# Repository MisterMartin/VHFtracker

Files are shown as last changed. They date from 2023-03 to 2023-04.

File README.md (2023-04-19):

# VHFtracker

Based on Teensy support provided by PJRC.

## Arduino Configuration
- Select the Teensy 3.6 board.
- Set the CPU speed to 24MHz.
## Hardware Revisions

Different I/O pins were used for some functions. A #define in the Arduino
sketch is used to select the targeted board.

| Rev A | Rev B |REV A Pin|REV B Pin| Notes |
|---|---|---|---|---|
| 0_RX1_(GPS_TX) | 33_TX5_(GPS_RX) | 0*  | 33*  | Selected as Serial1 or Serial5 |
| 1_TX1_(GPS_RX) | 34_RX5_(GPS_TX) | 1*  | 34*  | Selected as Serial1 or Serial5 |
| 2_TX_ENABLE | 16_TX_ENABLE | 2*  | 16*  | |
| A21_TX_AUDIO | DAC0 | 21 | 21 | |
| 18_SDA0_(PRESS)| (N/A) | 18 | | |
| 19_SCL0_(PRESS)| (N/A) | 19 | | |
| A6_3V7_VMON |(VMON UNLABELED) | 20 | 20 | |
| 23_5V_SHTDWN | 15_5V_SHTDWN | 23*  | 15*  | |
| 30_GPS_PWR_EN  | 36_GPS_PWR_EN | 30*  | 36*  | |
| 31_GPS_EXTINT  | | 31 | | How is this handled for Rev B? |
| 32_GPS_RST | | 32 | | How is this handled for Rev B? |

\* = signals that must be (re)defined based on the board revision.
## Arduino IDE

- The previous IDE was a pre-packaged by PRJC, as a modified version of Arduino IDE v1.x, 
  and ran as Teensyduino.
- PJRC released a board support package which now works with Arduino IDE v2.X. Install the
  Arduino IDE first, and then configure Teensy support, found on 
  the [PRJC download page](https://www.pjrc.com/teensy/td_download.html).
- For some reason, the board manager wouldn't read the PRJC board URL. I experimented with
  manually editing ~/.arduinoIDE/arduino-cli.yaml to add the URL, and restarting the 
  IDE multiple times. It finally read the URL and provided the Teensy in the boards list.
  Perhaps the issue was due to the slow Internet access from McMurdo.

## Tracker Code

- It turned out that the +5V control was not being used for the encoded ping. For Rev A,
  the ping was working because although the 5V shutdown was disabling the 5V regulator,
  power was still available to the op amp via a bypass diode. The switch that was added
  in Rev B prevented this, and the ping was not working. Once the code was corrected,
  the ping started working.

## Batteries

- In the 2019 deployment, a couple of the trackers failed because the commercial battery
  holders were breaking during landing impact. New holders were designed and fabricated on
  the 3d printer. Three designs were created and printed:
    - For Rev A: a single D cell holder for a battery with welded tabs. Hot glue holds the
      battery in at the open end.
    - For Rev B: a holder for 4 AA cells, with open ends for batteries with soldered/welded
      connections. Our batteries would not take solder, so these wer not used.
    - For Rev B: a holder for 4 AA cells, with no openings. Salvaged steel strips were used
      to make contacts. This design was flown.

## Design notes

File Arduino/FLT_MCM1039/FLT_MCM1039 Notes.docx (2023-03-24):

• Software changed: June 19, 2019

• PWB S/N: 409

• R1 removed

• Jumper SJ1 set for battery power

• Flight name\mode messages

• PRE_MSG "1038_PRE"

• TRK_MSG "1038_TRK"

• TRK_GPS "1038_GPS"

• PING_ID 38

• Timing parameters for the flight

• PreFlight Time = 2 hours (120 minutes), APRS XMIT every 10 minutes

• PREFLIGHT_APRS_TX_PERIOD 10

• MAX_PREFLIGHT_PACKETS 12

• 10*12 = 120

• GPS search time: 2 minutes

• Flight Time = 2 hours

• FLIGHT_TIME 120

• GPS search time: 2 minutes

• Hibernate\Sleep time

• Launch: March 29, 2023, Julian Day: 88

• Wake up: November 16, 2023, Julian Day: 320

• Number of days to hibernate 320 – 88 = 232

• HIBERNATE_PERIOD 232

• GPS search time: 5 minutes

• Track mode

• Update GPS position every 24 hours

• TRACK_GPS_PERIOD 24

• Send APRS GPS position every 10 minutes when in Track mode

• TRACK_APRS_TX_PERIOD 10

• Send pings every 15 seconds when in Track mode

• TRACK_PING_TX_PERIOD 15

• Three Audio pings 75 msec at 700 Hz per minute

• One encoded data ping per minute

• GPS search time: 3 minutes

Changes from FLT_1036

• None

Initial Power up Test

• Five Flashes

• First three messages after power up:

10:10:31, PRE__FLT, 000/001, 0000.00N, 00000.00E

10:21:00, 1037_PRE, 000/002, 7750.86S, 16639.94E

10:31:01, 1037_PRE, 000/003, 7750.86S, 16639.94E

• GPS position is correct

• Crary Lab: 77° 50.86’ (77.847°), 166° 39.96’ (166.666°)

13 June 2019

• Initial Battery Voltage = 3.658V

• Super Capacitor Charge Voltage = 3.696V

• Battery voltage after initial power on test = 3.568V

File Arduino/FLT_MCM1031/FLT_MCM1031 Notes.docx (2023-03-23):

FLT_MCM1031

- Software changed: May 28, 2019
- PWB S/N: 404
  - R1 removed
  - Jumper SJ1 set for battery power
- Flight name\mode messages
  - PRE_MSG "1031_PRE"
  - TRK_MSG "1031_TRK"
  - TRK_GPS "1031_GPS"
  - PING_ID 31
- Timing parameters for the flight
  - PreFlight Time = 2 hours (120 minutes), APRS XMIT every 10 minutes
    - PREFLIGHT_APRS_TX_PERIOD 10
    - MAX_PREFLIGHT_PACKETS 12
    - 10*12 = 120
    - GPS search time: 2 minutes
  - Flight Time = 2 hours
    - FLIGHT_TIME 120
    - GPS search time: 2 minutes
  - Hibernate\Sleep time
    - Launch: Wednesday, May 29, 2019, Julian Day: 149
    - Wake up: Friday, November 1, 2019, Julian Day: 305
    - Number of days to hibernate 305 – 149 = 156
    - HIBERNATE_PERIOD 156
    - GPS search time: 5 minutes
  - Track mode
    - Update GPS position every 24 hours
      - TRACK_GPS_PERIOD 24
    - Send APRS GPS position every 10 minutes when in Track mode
      - TRACK_APRS_TX_PERIOD 10
    - Send pings every 15 seconds when in Track mode
      - TRACK_PING_TX_PERIOD 15
      - Three Audio pings 75 msec at 700 Hz per minute
      - One encoded data ping per minute
    - GPS search time: 3 minutes

Changes from FLT_1030

- Changed Output_Ping_tone() function so it passes tone frequency and tone pulse length parameters
- Changed audio ping from 500 Hz to 704 Hz
  - 704 Hz seems more audible than 500 Hz

Initial Power up Test

- Five Flashes
- First three messages after power up:

9:18:19, PRE__FLT, 000/001, 0000.00N, 00000.00E

9:29:59, 1031_PRE, 000/002, 7750.86S, 16639.94E

9:40:00,1 031_PRE, 000/003, 7750.86S, 16639.94E

- GPS position is correct
  - Crary Lab: 77° 50.86 (77.847°), 166° 39.94’ (166.665°),

28 May 2019

- Initial Battery Voltage = 3.657V
- Super Capacitor Charge Voltage = 3.700V
- Installed initial battery voltage = 3.664 V
- Installed battery and plugged in voltage = 3.600 V

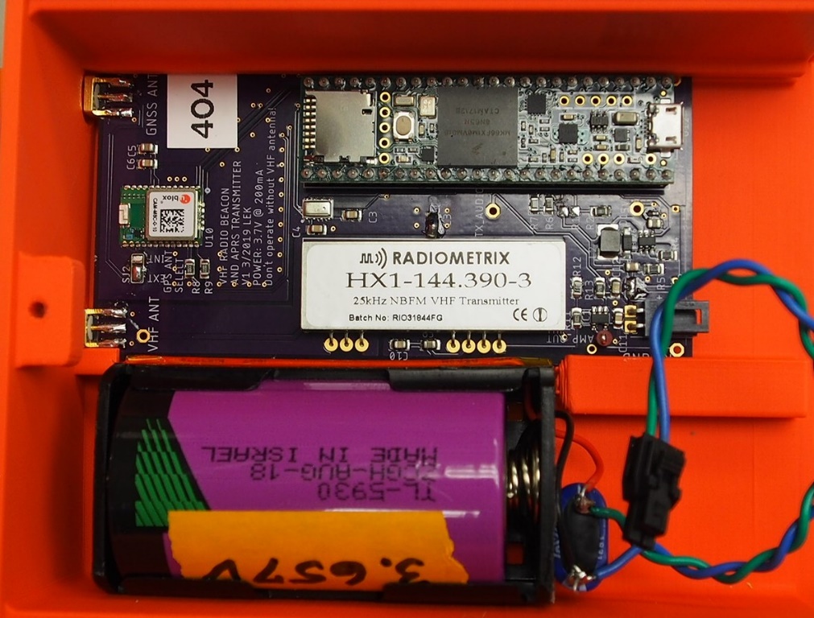
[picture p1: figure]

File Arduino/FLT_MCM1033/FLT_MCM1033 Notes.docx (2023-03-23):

- Software changed: June 7, 2019
- PWB S/N: 408
  - R1 removed
  - Jumper SJ1 set for battery power
- Flight name\mode messages
  - PRE_MSG "1033_PRE"
  - TRK_MSG "1033_TRK"
  - TRK_GPS "1033_GPS"
  - PING_ID 33
- Timing parameters for the flight
  - PreFlight Time = 2 hours (120 minutes), APRS XMIT every 10 minutes
    - PREFLIGHT_APRS_TX_PERIOD 10
    - MAX_PREFLIGHT_PACKETS 12
    - 10*12 = 120
    - GPS search time: 2 minutes
  - Flight Time = 2 hours
    - FLIGHT_TIME 120
    - GPS search time: 2 minutes
  - Hibernate\Sleep time
    - Launch: June 8, 2019, Julian Day: 159
    - Wake up: November 16, 2019, Julian Day: 320
    - Number of days to hibernate 320 – 159 = 161
    - HIBERNATE_PERIOD 166
    - GPS search time: 5 minutes
  - Track mode
    - Update GPS position every 24 hours
      - TRACK_GPS_PERIOD 24
    - Send APRS GPS position every 10 minutes when in Track mode
      - TRACK_APRS_TX_PERIOD 10
    - Send pings every 15 seconds when in Track mode
      - TRACK_PING_TX_PERIOD 15
      - Three Audio pings 75 msec at 700 Hz per minute
      - One encoded data ping per minute
    - GPS search time: 3 minutes

Changes from FLT_1031

- None
- Note: FLT 1032 was an ROPC flight and had no VHF tracker

Initial Power up Test

- Five Flashes
- First three messages after power up:

9:22:21, PRE__FLT, 000/001, 0000.00N, 00000.00E

9:33:01, 1033_PRE, 000/002, 7750.86S, 16639.94E

9:43:02, 1033_PRE, 000/003, 7750.86S, 16639.94E

- GPS position is correct
  - Crary Lab: 77° 50.86’ (77.847°), 166° 39.94’ (166.665°)

29 May 2019

- Initial Battery Voltage = 3.650V
- Super Capacitor Charge Voltage = 3.690V
- Installed initial battery voltage = 3.664 V
- Battery voltage after initial power on test = 3.583 V

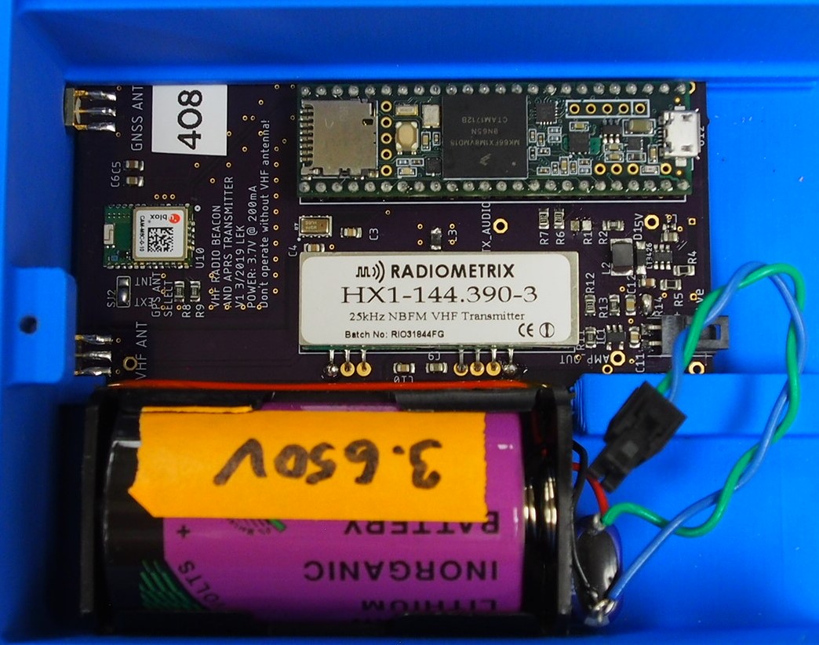
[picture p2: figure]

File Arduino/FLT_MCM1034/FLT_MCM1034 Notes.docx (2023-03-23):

- Software changed: June 7, 2019
- PWB S/N: 405
  - R1 removed
  - Jumper SJ1 set for battery power
- Flight name\mode messages
  - PRE_MSG "1034_PRE"
  - TRK_MSG "1034_TRK"
  - TRK_GPS "1034_GPS"
  - PING_ID 34
- Timing parameters for the flight
  - PreFlight Time = 2 hours (120 minutes), APRS XMIT every 10 minutes
    - PREFLIGHT_APRS_TX_PERIOD 10
    - MAX_PREFLIGHT_PACKETS 12
    - 10*12 = 120
    - GPS search time: 2 minutes
  - Flight Time = 2 hours
    - FLIGHT_TIME 120
    - GPS search time: 2 minutes
  - Hibernate\Sleep time
    - Launch: June 8, 2019, Julian Day: 159
    - Wake up: November 16, 2019, Julian Day: 320
    - Number of days to hibernate 320 – 159 = 161
    - HIBERNATE_PERIOD 161
    - GPS search time: 5 minutes
  - Track mode
    - Update GPS position every 24 hours
      - TRACK_GPS_PERIOD 24
    - Send APRS GPS position every 10 minutes when in Track mode
      - TRACK_APRS_TX_PERIOD 10
    - Send pings every 15 seconds when in Track mode
      - TRACK_PING_TX_PERIOD 15
      - Three Audio pings 75 msec at 700 Hz per minute
      - One encoded data ping per minute
    - GPS search time: 3 minutes

Changes from FLT_1031

- None
- Note: FLT 1032 was an ROPC flight and had no VHF tracker

Initial Power up Test

- Five Flashes
- First three messages after power up:

8:54:00, PRE__FLT, 000/001, 0000.00N, 00000.00E

9:04:00, 1033_PRE, 000/002, 7750.86S, 16639.94E

9:14:00, 1033_PRE, 000/003, 7750.86S, 16639.94E

- GPS position is correct
  - Crary Lab: 77° 50.86’ (77.847°), 166° 39.98’ (166.666°)

30 May 2019

- Initial Battery Voltage = 3.658V
- Super Capacitor Charge Voltage = 3.698V
- Installed initial battery voltage = 3.600 V
- Battery voltage after initial power on test = 3.595 V

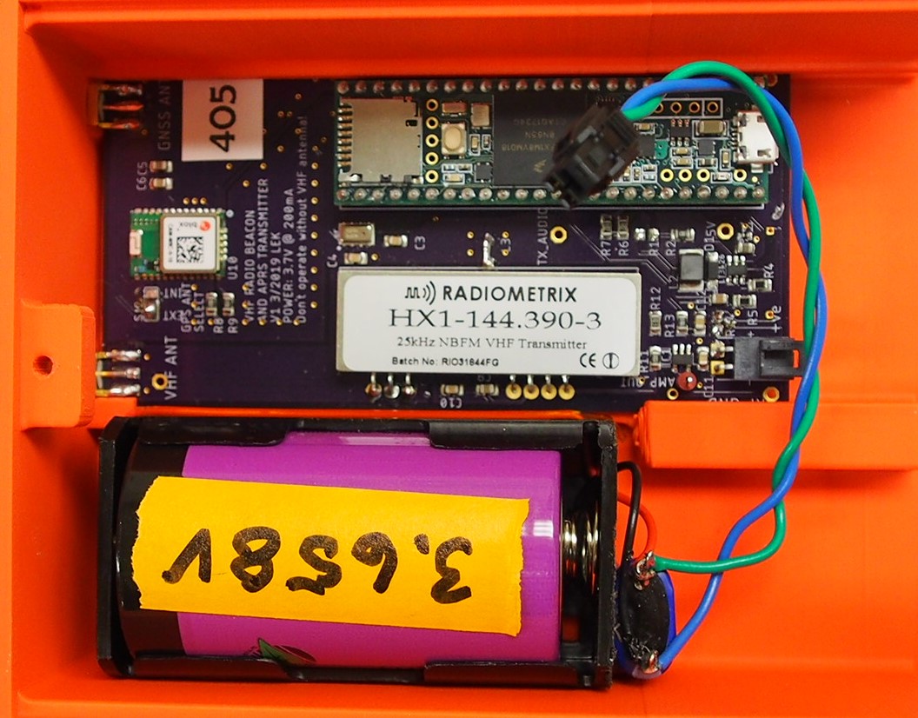
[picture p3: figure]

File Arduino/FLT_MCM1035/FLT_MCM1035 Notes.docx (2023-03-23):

- Software changed: June 19, 2019
- PWB S/N: 407
  - R1 removed
  - Jumper SJ1 set for battery power
- Flight name\mode messages
  - PRE_MSG "1035_PRE"
  - TRK_MSG "1035_TRK"
  - TRK_GPS "1035_GPS"
  - PING_ID 35
- Timing parameters for the flight
  - PreFlight Time = 2 hours (120 minutes), APRS XMIT every 10 minutes
    - PREFLIGHT_APRS_TX_PERIOD 10
    - MAX_PREFLIGHT_PACKETS 12
    - 10*12 = 120
    - GPS search time: 2 minutes
  - Flight Time = 2 hours
    - FLIGHT_TIME 120
    - GPS search time: 2 minutes
  - Hibernate\Sleep time
    - Launch: June 24, 2019, Julian Day: 175
    - Wake up: November 16, 2019, Julian Day: 320
    - Number of days to hibernate 320 – 175 = 145
    - HIBERNATE_PERIOD 145
    - GPS search time: 5 minutes
  - Track mode
    - Update GPS position every 24 hours
      - TRACK_GPS_PERIOD 24
    - Send APRS GPS position every 10 minutes when in Track mode
      - TRACK_APRS_TX_PERIOD 10
    - Send pings every 15 seconds when in Track mode
      - TRACK_PING_TX_PERIOD 15
      - Three Audio pings 75 msec at 700 Hz per minute
      - One encoded data ping per minute
    - GPS search time: 3 minutes

Changes from FLT_1034

- None

Initial Power up Test

- Five Flashes
- First three messages after power up:

14:25:15, PRE__FLT, 000/001, 0000.00N,00000.00E

14:35:48, 1035_PRE, 000/002, 7750.86S,16639.96E

14:45:49, 1035_PRE, 000/003, 7750.86S,16639.96E

- GPS position is correct
  - Crary Lab: 77° 50.86’ (77.847°), 166° 39.96’ (166.666°)

31 May 2019

- Initial Battery Voltage = 3.658V
- Super Capacitor Charge Voltage = 3.698V
- Installed initial battery voltage = 3.600 V
- Battery voltage after initial power on test = 3.584 V

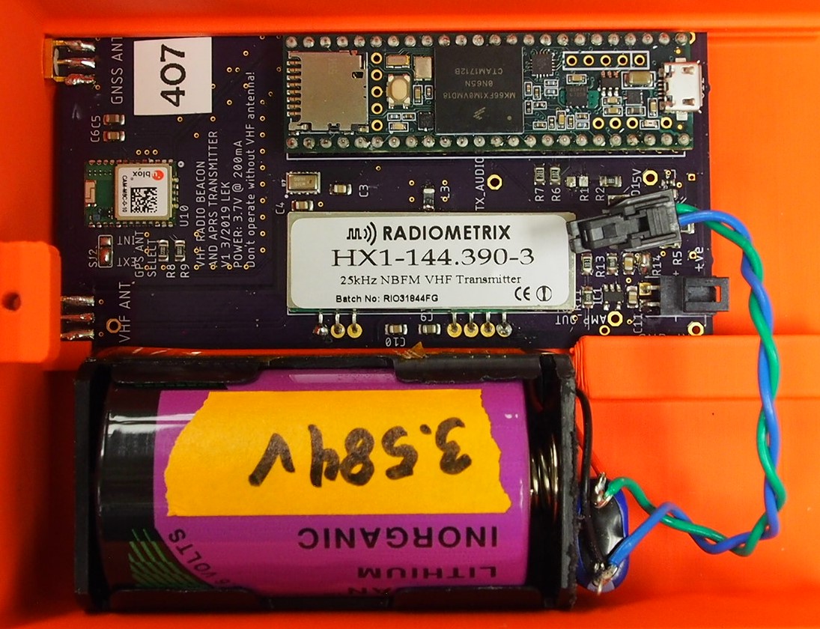
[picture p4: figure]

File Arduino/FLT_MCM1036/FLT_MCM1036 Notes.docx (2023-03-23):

- Software changed: June 19, 2019
- PWB S/N: 402
  - R1 removed
  - Jumper SJ1 set for battery power
- Flight name\mode messages
  - PRE_MSG "1036_PRE"
  - TRK_MSG "1036_TRK"
  - TRK_GPS "1036_GPS"
  - PING_ID 36
- Timing parameters for the flight
  - PreFlight Time = 2 hours (120 minutes), APRS XMIT every 10 minutes
    - PREFLIGHT_APRS_TX_PERIOD 10
    - MAX_PREFLIGHT_PACKETS 12
    - 10*12 = 120
    - GPS search time: 2 minutes
  - Flight Time = 2 hours
    - FLIGHT_TIME 120
    - GPS search time: 2 minutes
  - Hibernate\Sleep time
    - Launch: June 24, 2019, Julian Day: 175
    - Wake up: November 16, 2019, Julian Day: 320
    - Number of days to hibernate 320 – 175 = 145
    - HIBERNATE_PERIOD 145
    - GPS search time: 5 minutes
  - Track mode
    - Update GPS position every 24 hours
      - TRACK_GPS_PERIOD 24
    - Send APRS GPS position every 10 minutes when in Track mode
      - TRACK_APRS_TX_PERIOD 10
    - Send pings every 15 seconds when in Track mode
      - TRACK_PING_TX_PERIOD 15
      - Three Audio pings 75 msec at 700 Hz per minute
      - One encoded data ping per minute
    - GPS search time: 3 minutes

Changes from FLT_1035

- None

Initial Power up Test

- Five Flashes
- First three messages after power up:

9:12:53, PRE__FLT, 000/001, 0000.00N, 00000.00E

9:24:55, 1036_PRE, 000/002, 7750.86S, 16639.96E

9:34:55, 1036_PRE, 000/003, 7750.86S, 16639.96E

- GPS position is correct
  - Crary Lab: 77° 50.86’ (77.847°), 166° 39.96’ (166.666°)

10 June 2019

- Initial Battery Voltage = 3.657V
- Super Capacitor Charge Voltage = 3.698V
- Battery voltage after initial power on test = 3.568V

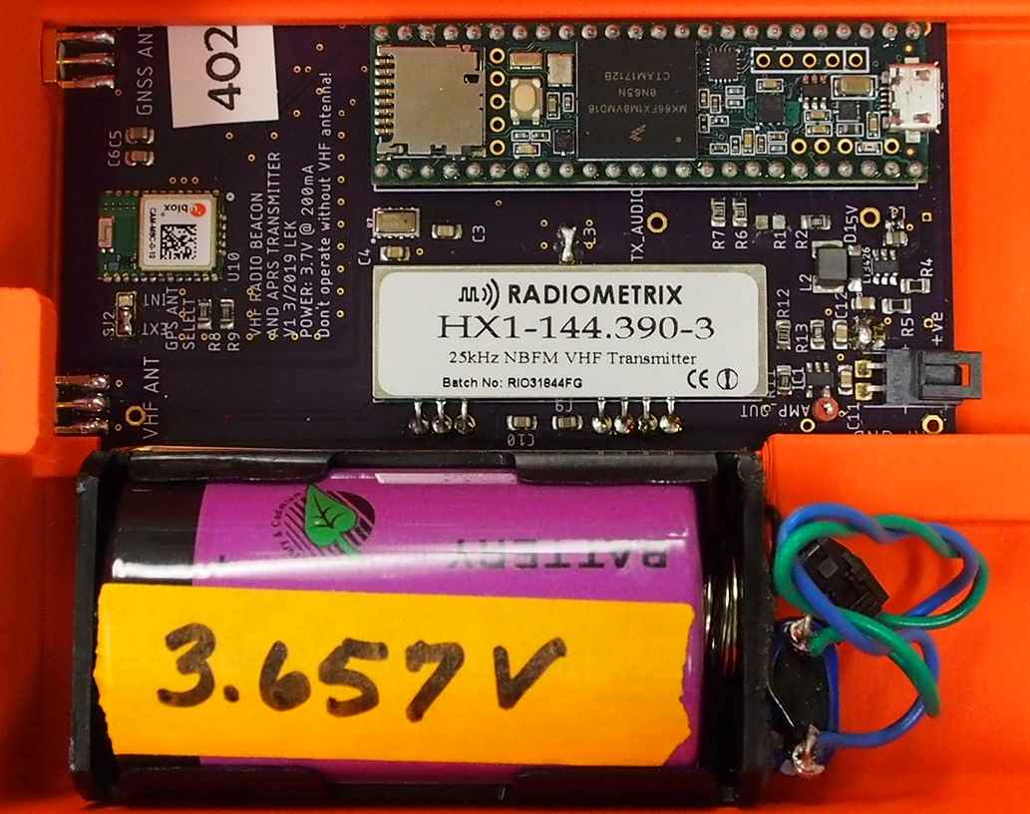
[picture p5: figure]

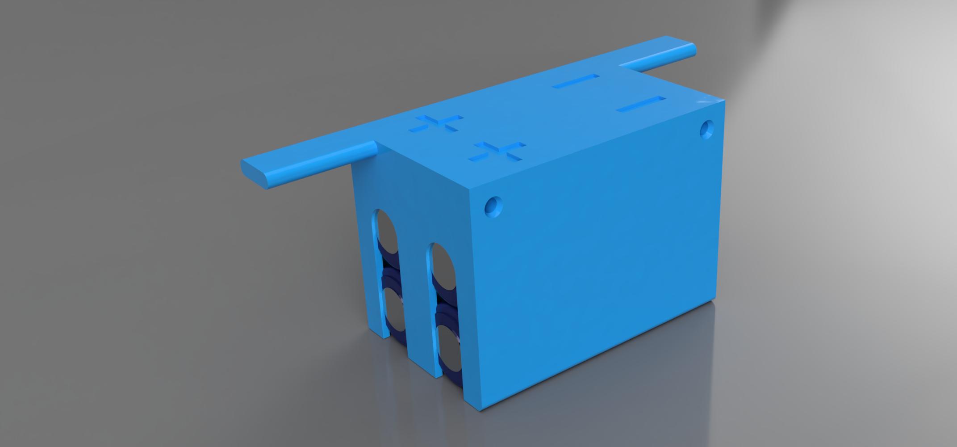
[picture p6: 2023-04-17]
Battery Holders/RevB/Render01.png

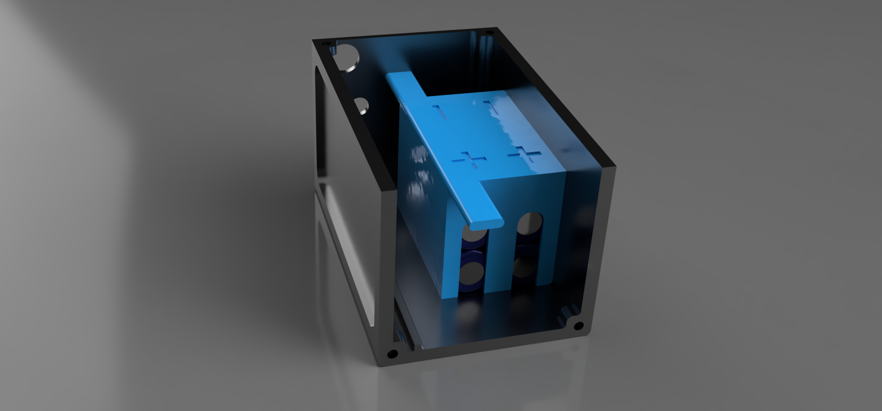
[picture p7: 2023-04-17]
Battery Holders/RevB/Render03.png

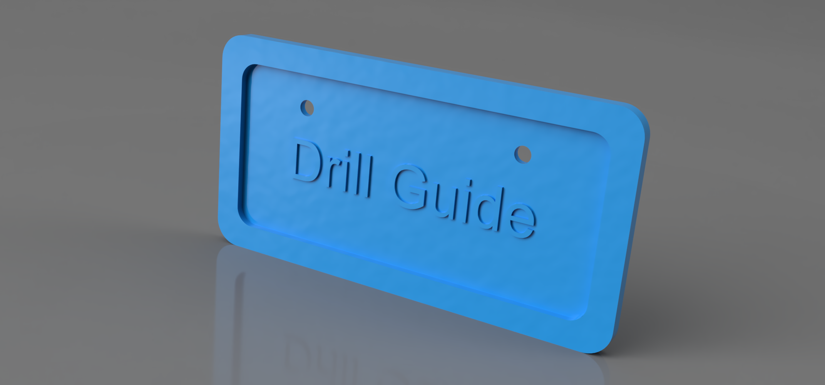
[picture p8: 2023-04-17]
Battery Holders/RevB/Render02.png

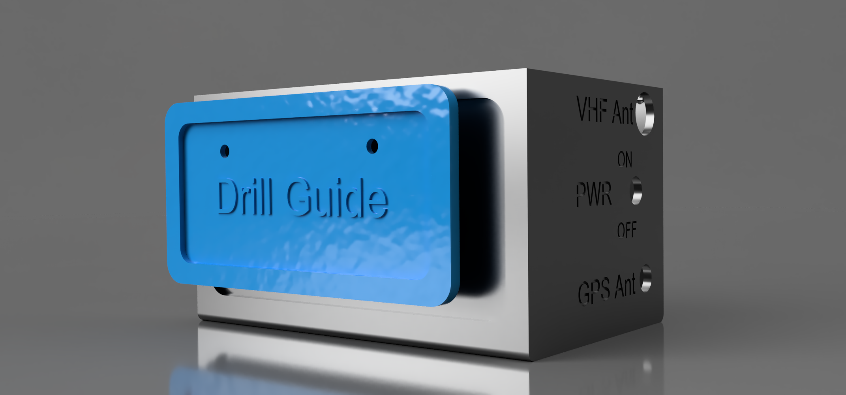
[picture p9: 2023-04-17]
Battery Holders/RevB/Render04.png

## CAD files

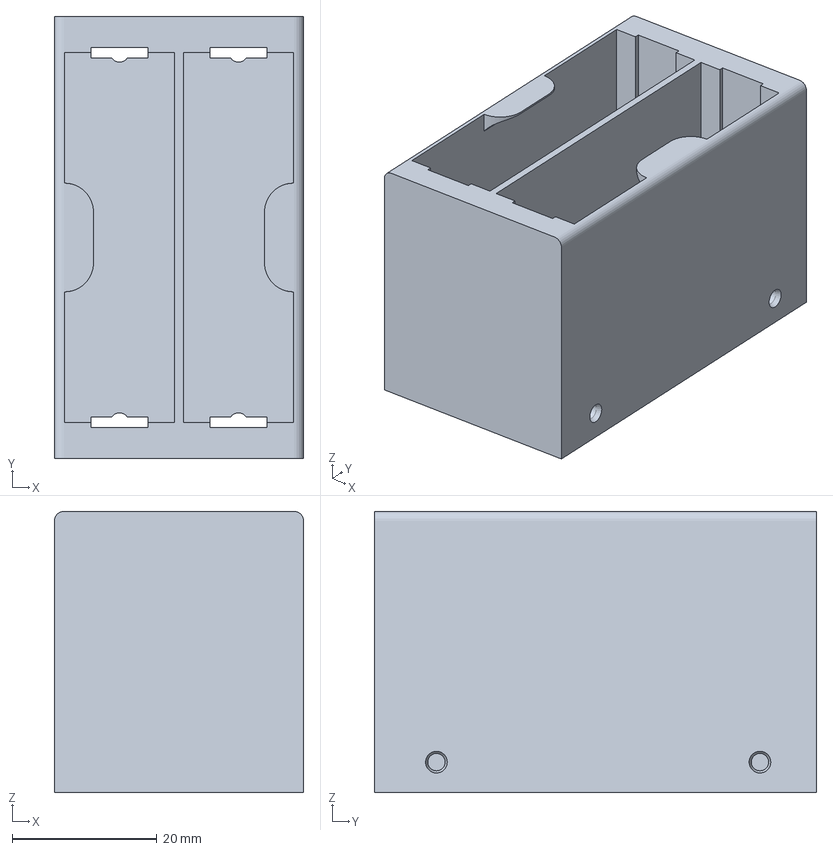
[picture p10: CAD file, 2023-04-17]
Battery Holders/RevB/RevB Bat Box Mk II v36.3mf
34.4 x 61.0 x 38.8 mm

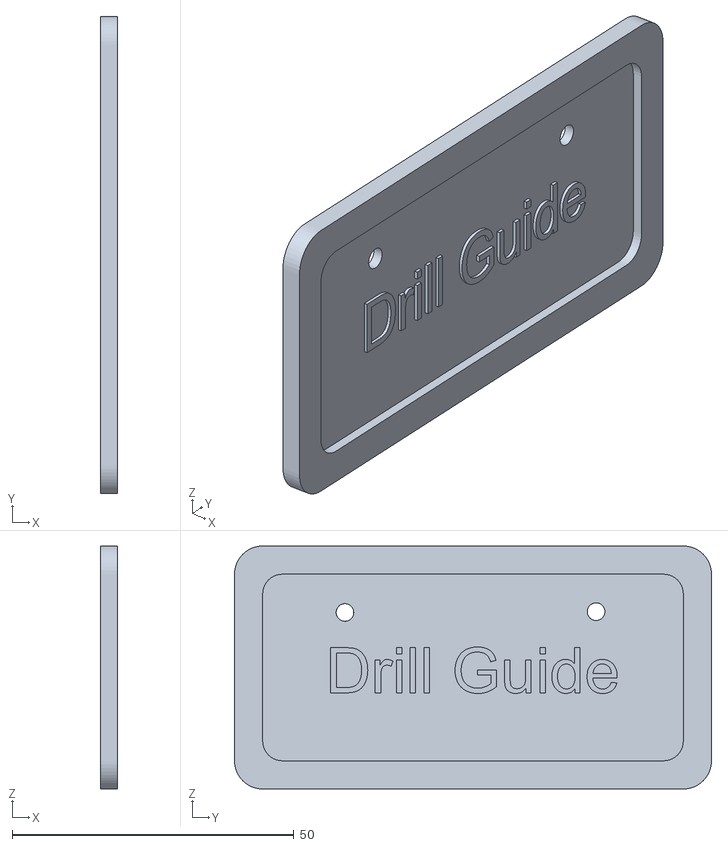
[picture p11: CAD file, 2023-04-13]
Battery Holders/RevB/Rev B Battery Holder Drill Guide v98.stl
3.00 x 84.6 x 43.1

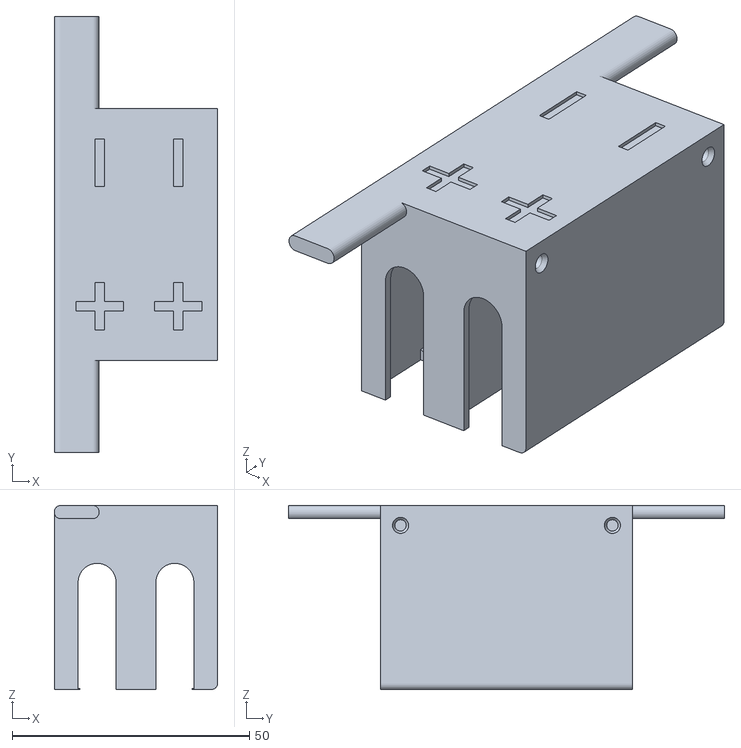
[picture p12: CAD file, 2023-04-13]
Battery Holders/RevB/Rev B Battery Holder v99.stl
34.4 x 91.9 x 38.8

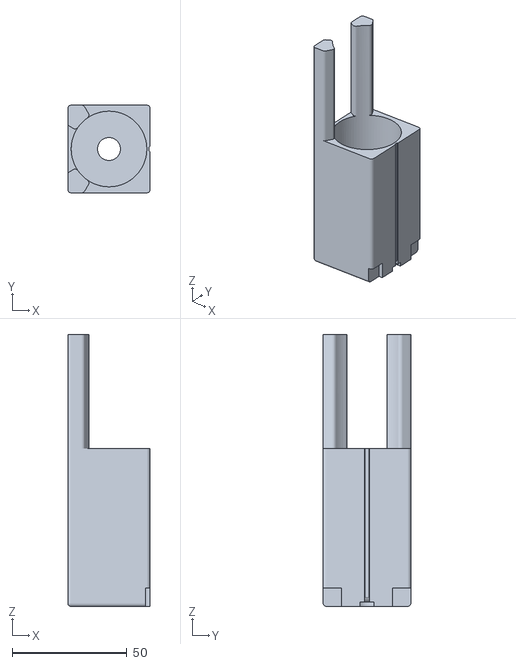
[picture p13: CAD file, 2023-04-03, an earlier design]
Battery Holders/RevA/Battery Holder v27.stl
36.0 x 38.3 x 118.7

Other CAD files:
Battery Holders/RevA/Battery Holder v27.f3d
Battery Holders/RevB/RevB Bat Box Mk II v36.stl

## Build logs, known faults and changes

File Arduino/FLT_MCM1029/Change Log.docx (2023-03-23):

APRS_MM1029 Notes

- Software changed: May 1, 2019
- PWB S/N: 403
- Timing parameters for the flight
  - #define FLIGHT_NAME "MCM1029"
  - Flight Time = 1 hour (60 minutes), APRS XMIT every 10 minutes
    - #define FLIGHT_PERIOD 60
    - #define FLIGHT_APRS_TX_PERIOD 10
  - Hibernate\Sleep time
    - Launch: Wednesday, May 1, 2019, Julian Day: 121
    - Wake up: Friday, November 1, 2019, Julian Day: 305
    - Number of days to hibernate 305 – 121 = 184
    - #define HIBERNATE_PERIOD 184
  - Update GPS position every 24 hours when in Track mode
    - #define TRACK_GPS_PERIOD 24
  - Send APRS GPS position every 15 minutes when in Track mode
    - #define TRACK_APRS_TX_PERIOD 15
  - Send 1 KHz ping every 15 seconds when in Track mode
    - #define TRACK_PING_TX_PERIOD 15
  - Make 1 KHz ping 100 msec long
    - #define PING_DURATION 1000
    - Ping time (msec) = PING_DURATION/10
- Deleted 500 msec delay at the end Mode 2 code in the main loop
  - Used for debug and not used or needed in flight mode

if (mode == 2)

{

ping(PING_DURATION); //send a ping

if(pings_sent * TRACK_PING_TX_PERIOD > TRACK_APRS_TX_PERIOD * 60) // if it is time to send an APRS, send it using the existing GPS position

{

broadcastLocation( FLIGHT_NAME ); //Send the location by APRS

track_APRS_packets ++;

pings_sent = 0; //reset ping counter

}

if(track_APRS_packets * TRACK_APRS_TX_PERIOD > TRACK_GPS_PERIOD * 60) //if it is time to update GPS, update the position

{

getGPS(180); //try for 3 minutes to get a GPS Position

}

alarm.setRtcTimer(0, 0, TRACK_PING_TX_PERIOD); // hour, min, sec go back to sleep until the next ping

Snooze.hibernate( config_teensy36 );

}

~~delay(~~~~500);~~

}

Initial Power up Test After Programming (USB Powered)

- Five Flashes
- First Msg: “00000TRACKER_ON_FLT”
  - Programmed to TRACKER_ON_MODE=FLT
- Second Message: “000000MM1029”
  - Flt position message time: 1536
  - Next Flt position message time: 1546
  - Δt = 10 minutes

Power up with test battery

- GPS position is correct
  - Crary Lab: 77° 50.89’, 166° 40.13’,
- Position updates correctly

1 May 2019

- Initial Battery Voltage = 3.655V
- Super Capacitor Charge Voltage = 3.700V
- Installed initial battery voltage = 3.664 V
- Installed battery and plugged in voltage = 3.500 V

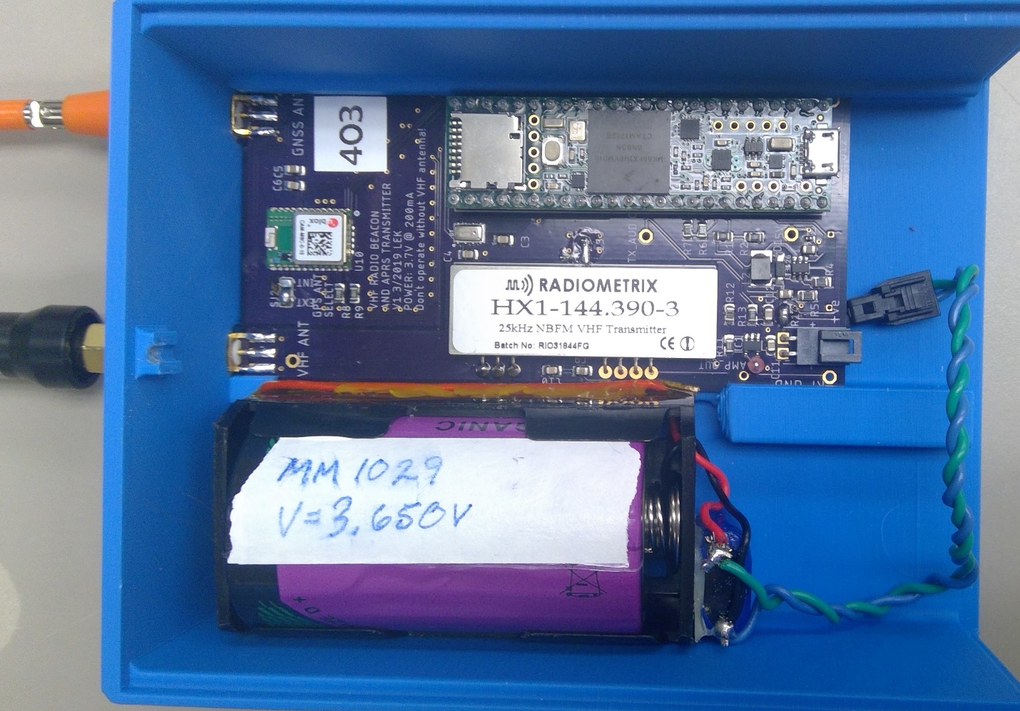
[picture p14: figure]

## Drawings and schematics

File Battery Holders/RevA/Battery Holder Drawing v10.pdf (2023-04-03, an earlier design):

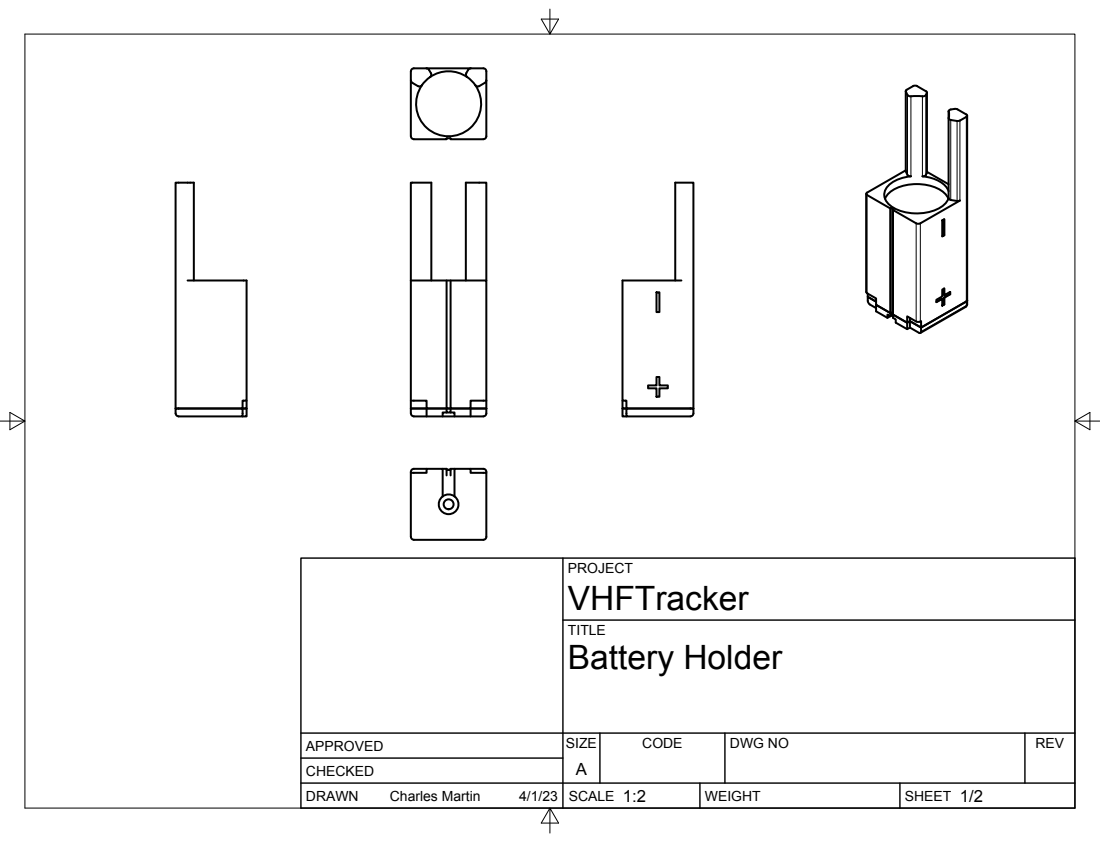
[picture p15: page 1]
SIZE; CODE; DWG NO; REV; Charles Martin; Battery Holder

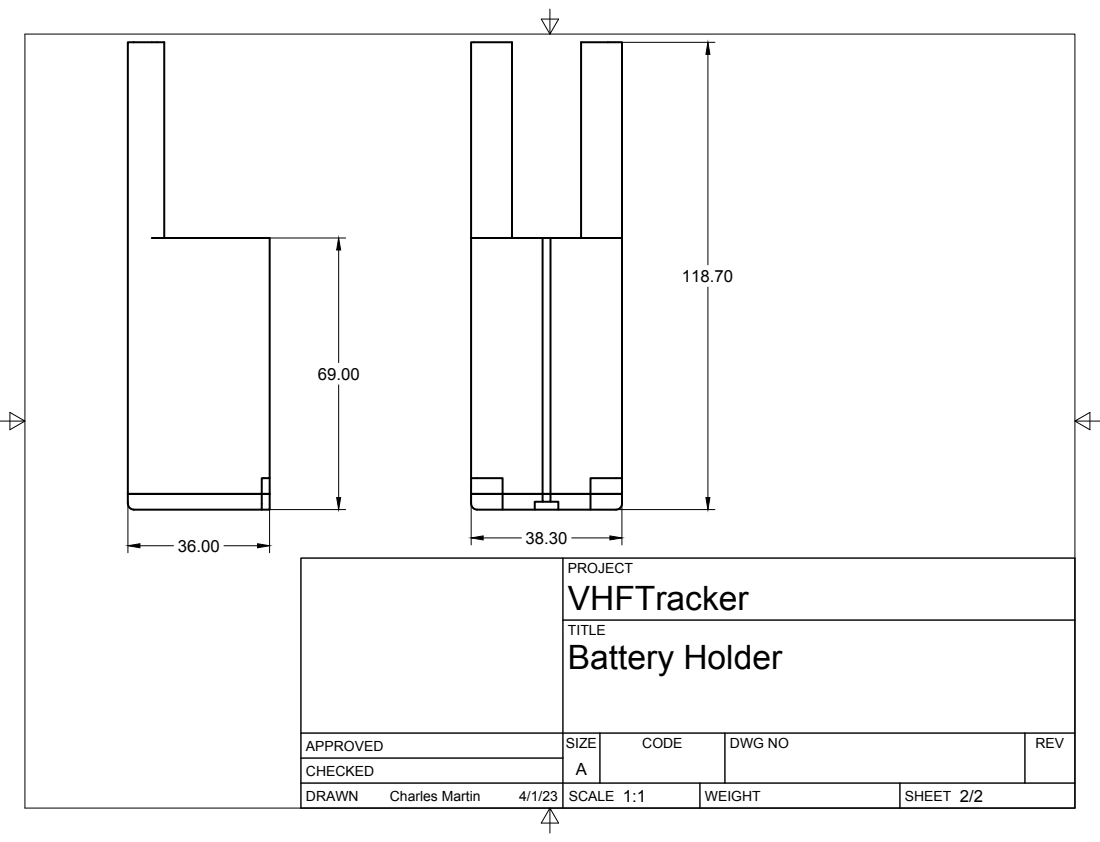
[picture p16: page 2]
SIZE; CODE; DWG NO; REV; Charles Martin; Battery Holder

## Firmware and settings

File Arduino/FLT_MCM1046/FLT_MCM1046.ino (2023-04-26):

// Automatic Packet Rreporting System (APRS) 
// *** Compile at 24Mhz to minimize power consumption

//*************************************************************************
//             Configuration
// Tracker model. One or the other must be defined.
//#define TRACKER_REVA
#define TRACKER_REVB

#define FLIGHT_NUM "1046"             // MUST be 4 numeric characters, .e.g. "1030"
#define PING_ID    46                 // Ping ID (0-255) sent for ping ID byte (should be last two digits of the flight number)

// PREFLIGHT mode parameters
#define PREFLIGHT_APRS_TX_PERIOD 10   // (Default 10) How often to send an APRS position (minutes)
#define MAX_PREFLIGHT_PACKETS    12   // (Default 12) PREFLIGHT mode runs for 
                                      // (PREFLIGHT_APRS_TX_PERIOD)*(MAX_PREFLIGHT_PACKETS) (minutes)
                                      // (PREFLIGHT_APRS_TX_PERIOD=10)*(MAX_PREFLIGHT_PACKETS=12)= 10*12 = 120 minutes Preflight mode time
// FLIGHT mode parameters
#define FLIGHT_TIME 120               // (Default 120) How many minutes to remain in Flight Mode

// HIBERNATE parameters --- Launch Date: 27 April 2023 (JD 117), Wake Up Date: 01 Nov 2023 (JD 305)-----------
#define HIBERNATE_PERIOD        188   // Will Hibernate for 188 days

// TRACK mode parameters
#define TRACK_GPS_PERIOD         24   // (Default 24) How often to look for a GPS position (hours)
#define TRACK_APRS_TX_PERIOD     10   // (Default 10) How often to send APRS position message (minutes)
#define TRACK_PING_TX_PERIOD     15   // (Default 15) How often to send a Ping (seconds)
//*************************************************************************

// Note: for post processing reasons, make all APRS ASCII text message fields a fixed 8 characters long

#include <afsk.h>
#include <ax25.h>
#include <aprs.h>                 // APRS encoding and transmission library
#include <Wire.h> 
#include <Snooze.h>               // For low power hibernate
#include <TinyGPS++.h>            // GPS parsing library
#include <WProgram.h>

void ax25_send_flag();            // Forward definition, because it is not defined in ax25.h

// Load drivers for the snooze code and configure snooze block.  We only us the RTC alamr so that is all we need to load. 
SnoozeAlarm  alarm;
SnoozeBlock config_teensy36(alarm); 

TinyGPSPlus gps;

// Message headers for the APRS messages.
#define HEL_MSG    FLIGHT_NUM"_HEL"   // Power on APRS message says hello
#define PRE_MSG    FLIGHT_NUM"_PRE"   // Flight name in APRS preflight mode message
#define FLT_MSG    FLIGHT_NUM"_FLT"   // Flight name in APRS flight mode message
#define HIB_MSG    FLIGHT_NUM"_HIB"   // Flight name in APRS hibernate mode message
#define TRK_MSG    FLIGHT_NUM"_TRK"   // Flight name in APRS track mode message (sent every TRACK_APRS_TX_PERIOD)
#define TRK_GPS    FLIGHT_NUM"_GPS"   // Flight name in APRS track mode GPS message (sent every TRACK_GPS_PERIOD)

#define GPS_24bit_SF 93200     // approx (2^24)/180, used to scale decimal degrees to 24 bit integer

#define GPS_PWR_ON  1     // used in getGPS(long timeout, bool Power) function, leave GPS PWR on
#define GPS_PWR_OFF 0     // used in getGPS(long timeout, bool Power) function, Turn GPS PWR off when done

// mode definitions
#define PREFLIGHT 0       // Prefight mode, Accquire GPS location, send APRS often, no pings
#define FLIGHT    1       // Fight mode, Accquire GPS location, no APRS, no pings
#define HIBERNATE 2       // Hibernate mode, do nothing until wake up day
#define TRACK     3       // Track mode, Accquire GPS location, send APRS, send GPS and tone pings


// Pin usage revision dependencies
#ifdef TRACKER_REVA
#define GPSSERIAL Serial1       // UBlox GPS is on Serial1
/* Pin Configuration */
#define V_TX_SHUTDOWN 23        // Enable pin for 3.6 to 5V boost converter
#define V_GPS_SHUTDOWN 30       // Power switch on 3.3v line to GPS and Pressure Sensor
#define TX_ENABLE 2             // Pull this high to turn on the transmitter (Push To Talk function)
#endif

#ifdef TRACKER_REVB
#define GPSSERIAL Serial5       // UBlox GPS is on Serial1
/* Pin Configuration */
#define V_TX_SHUTDOWN 15        // Enable pin for 3.6 to 5V boost converter
#define V_GPS_SHUTDOWN 36       // Power switch on 3.3v line to GPS and Pressure Sensor
#define TX_ENABLE 16             // Pull this high to turn on the transmitter (Push To Talk function)
#endif

/* APRS Configuration */
// Set your callsign and SSID here. Common values for the SSID are
#define S_CALLSIGN      "KE0PRP"
#define S_CALLSIGN_ID   11          // 11 is usually for balloons
                                    // Destination callsign: APRS (with SSID=0) is usually okay.
#define D_CALLSIGN      "APRS"
#define D_CALLSIGN_ID   0
                                    // Symbol Table: '/' is primary table '\' is secondary table
#define SYMBOL_TABLE '/' 
                                    // Primary Table Symbols: /O=balloon, /-=House, /v=Blue Van, />=Red Car
#define SYMBOL_CHAR 'O'

struct PathAddress addresses[] = 
  {
    {(char *)D_CALLSIGN, D_CALLSIGN_ID},    // Destination callsign
    {(char *)S_CALLSIGN, S_CALLSIGN_ID},    // Source callsign
    {(char *)NULL, 0},                      // Digi1 (first digi in the chain)
    {(char *)NULL, 0}                       // Digi2 (second digi in the chain)
  };

// quarter wave sine table for tone generation
unsigned int Sine[26] =         // 26 samples for 1/4 sine wave
{2047,2177,2306,2434,2561,2686,2808,2927,3042,3154,3261,3363,3460,
 3551,3636,3715,3787,3852,3909,3960,4002,4037,4063,4082,4092,4094};

int Preflight_APRS_packets = 0;    // Preflight mode loop counter
int Hibernate_day = 0;             // number of days in hibernation
int track_APRS_packets = 1;        // used in Track Mode, counts the number of APRS packets sent in track mode
long pings_sent = 1;               // used in Track Mode, counts the number of pings sent in track mode
byte ping_state = 0;               // used in Track Mode, controlls the type of ping (tone or encoded position data) sent in track mode

long StartTime = 0;                   // Used in Flight Mode
long MaxTime = FLIGHT_TIME*1000*60;   // Maximum time to stay in Flight Mode, MaxTime(msec), FLIGHT_TIME(minutes)  
   
// 8 byte array (ID, FIX, LAT2, LAT1, LAT0, LON2, LON1, LON0) for sending binary GPS ping
byte Ping_Array[8] = {PING_ID, 0, 0x55, 0x55, 0x55, 0xAA, 0xAA, 0xAA};       // dummy values for testing (LAT=60.004, LON=120.008

unsigned long int Fix_Time =0;     // value uesd to send gps.location.age() to the radio using the ALT value displayed on the TH-D74 radio
byte APRS_XMIT_count = 0;          // increments when ever a APRS message is sent

int mode = PREFLIGHT;              // mode must be initialized to PREFLIGHT for all balloon flights

#ifdef TRACKER_REVA
char* board_revision = "Configured for board REV A";
#endif
#ifdef TRACKER_REVB
char* board_revision = "Configured for board REV B";
#endif
#if (!defined(TRACKER_REVA) && !defined(TRACKER_REVB)) || (defined(TRACKER_REVA) && (defined(TRACKER_REVB)))
#error "One of TRACKER_REVA or TRACKER_REVB must be defined."
#endif

//************************************************************************************************
//************************************************************************************************
void setup()
{
  Serial.begin(9600); // For debugging output over the USB port
  Serial.println(__FILE__);
  Serial.print("Build time: ");
  Serial.print(__TIMESTAMP__);
  Serial.print(" ");
  Serial.println(board_revision);

  /* GPS Setup */
   GPSSERIAL.begin(9600); //GPS receiver setup

   pinMode(LED_BUILTIN, OUTPUT);
   pinMode(V_TX_SHUTDOWN, OUTPUT);
   pinMode(V_GPS_SHUTDOWN, OUTPUT);
   pinMode(TX_ENABLE,OUTPUT);

   /* Start with everything off */
   digitalWrite(V_TX_SHUTDOWN, LOW);
   digitalWrite(V_GPS_SHUTDOWN, LOW);
   digitalWrite(TX_ENABLE, LOW);
   analogWriteResolution(12);
   analogReference(INTERNAL);

// Blink 5 times on power up so we know it is working */
  for (int i = 0; i < 5 ; i++)
  {
    digitalWrite(LED_BUILTIN, HIGH);
    delay(200);
    digitalWrite(LED_BUILTIN, LOW);
    delay(200);
  }
  
// Set up the APRS code
  aprs_setup(
       10,              // Send 10 APRS preamble flags (this is a WAG, but if needed can be longer to help TH-D74 sync), must be at least 2
       TX_ENABLE,       // Use PTT pin
       5,               // Wait 5 mesc after TX_ENABLE goes high to start sending data transmission
       0, 0             // No VOX ton
       );
  
  broadcastLocation(HEL_MSG);   // Send hello APRS message to the TH-D74 Tracker radio
}

//************************************************************************************************
//************************************************************************************************
void loop()
{
   //---------------------------------------------------------------------------------------------  
   // PREFLIGHT Mode: Only sends APRS positions, no pings. Attempts to update GPS position for every APRS packet sent
   //
   if (mode == PREFLIGHT) 
   {
      if (Preflight_APRS_packets < MAX_PREFLIGHT_PACKETS)     // Preflight mode will run for (MAX_PREFLIGHT_PACKETS)*(PREFLIGHT_APRS_TX_PERIOD) (in seconds)
        {        
         alarm.setRtcTimer(0, PREFLIGHT_APRS_TX_PERIOD,0);    // hour, min, sec
         Snooze.hibernate( config_teensy36 );
         getGPS(120,GPS_PWR_OFF);            // try for 2 minutes to get a GPS Position, turn GPS PWR off when done
         broadcastLocation(PRE_MSG);         // Send the location by APRS
         Preflight_APRS_packets++;        
        }
      else
        {
         broadcastLocation(FLT_MSG);      // Send "FLT_MODE" APRS message to the TH-D74 Tracker radio
         Ping_Array[1] = 0;               // Reset the counter that tracks the number of invalid GPS fixes
         APRS_XMIT_count = 0;             // Reset APRS message sent counter when changing modes
         mode = FLIGHT;                   // Go to FLIGHT mode when Preflight mode is completed
        }   
   }   

   //---------------------------------------------------------------------------------------------
   // FLIGHT MODE: Acquires and stores GPS postions only, No APRS messages or pings sent
   //              Stays in flight mode for FLIGHT_TIME (units: minutes)
   //
     if (mode == FLIGHT)
      {
        StartTime = millis();
            
        while (millis()-StartTime < MaxTime)    // continously update the GPS position while in FLIGHT mode
         {
          getGPS(120,GPS_PWR_ON);               // try for 2 minutes to get a GPS Position, Leave GPS PWR ON
         }                                                   
      
        digitalWrite(V_GPS_SHUTDOWN, LOW);      // Always turn off GPS Power when leaving FLIGHT mode
        broadcastLocation(HIB_MSG);             // Send "HIB_MODE" APRS message to the TH-D74 Tracker radio
        Ping_Array[1] = 0;                      // Reset the counter that tracks the number of invalid GPS fixes
        APRS_XMIT_count = 0;                    // Reset APRS message sent counter when changing modes
        mode = HIBERNATE;                       // Go to HIBERNATE mode when flight mode is completed
      } 

  //---------------------------------------------------------------------------------------------
  // HIBERNATE MODE: Wakes up once per day to increment the days in hibernate counter
  //                 Gets a GPS postion when the hibernate period is complete
  //
  //    Hibernation function: alarm.setRtcTimer(Hours, minutes, seconds)
  //
  if (mode == HIBERNATE) 
   {
      if (Hibernate_day < HIBERNATE_PERIOD)      // stay in Hibernate until hibernate period is complete
        {
         alarm.setRtcTimer(24, 0, 0);            // Set Timer to 24 hours, 0 minutes, 0 seconds to go to sleep for a day
         Snooze.hibernate( config_teensy36 );
         Hibernate_day ++;                       // number of days in hibernate   
        }
       else
        {
         getGPS(300,GPS_PWR_OFF);         // try for 5 minutes to get a GPS Position                                                             
         broadcastLocation(TRK_MSG);      // Send "TRK_MODE" APRS message to the TH-D74 Tracker radio
         APRS_XMIT_count = 0;             // Reset APRS message sent counter when changing modes
         mode = TRACK;                    // Go to TRACK mode when hibernate period completed    
        }  
   }

   //---------------------------------------------------------------------------------------------
   // TRACK MODE: Updates GPS position and sends APRS message every TRACK_GPS_PERIOD (hours)
   //             Sends APRS message every TRACK_APRS_TX_PERIOD (minutes)
   //             Sends pings every TRACK_PING_TX_PERIOD (seconds)
   //
   if (mode == TRACK) 
   {
     if((pings_sent*TRACK_PING_TX_PERIOD) >= TRACK_APRS_TX_PERIOD * 60)      // if it is time, send an APRS message   
       {
          if(track_APRS_packets * TRACK_APRS_TX_PERIOD >= TRACK_GPS_PERIOD * 60)     // If it is time, update the GPS position 
            {
              getGPS(180,GPS_PWR_OFF);      // try for 3 minutes to get a GPS Position
              broadcastLocation(TRK_GPS);   // Send the new GPS location by APRS and indicate a GPS cycle
              track_APRS_packets = 1;       // Reset track_APRS_packets counter after the GPS position has been updated
            }
          else
            {
              broadcastLocation(TRK_MSG);  // Send the existing GPS location by APRS and indicate a TRK cycle
              track_APRS_packets++;        // increment the counter that keeps track of the number of APRS messages sent               
            }   
          pings_sent = 1;                  // Reset ping counter after every APRS meesage
          ping_state = 0;                  // first ping after any APRS message is a tone
       }
      else                          // Send a Ping if no APRS message was sent
       {
         pings_sent++;              // increment the counter for number of pings sent
         
         switch (ping_state)        // send three tone and one encoded GPS pings for every TRACK_PING_TX_PERIOD
          {                            
            case 0:
              Output_Ping_tone(11,53);  // 704 Hz tone for 75 msec
              ping_state++;             // goto next state
              break;
            case 1:
              Output_Ping_tone(11,53);  // 704 Hz tone for 75 msec
              ping_state++;             // goto next state
              break; 
            case 2:
              Output_Ping_tone(11,53);  // 704 Hz tone for 75 msec
              ping_state++;             // goto next state
              break;        
            case 3:
              EncodedPing();            // Send encoded GPS position track ping     
              ping_state = 0;           // goto state 0
              break;                               
            default: 
              ping_state = 0;       // goto state 0 (should never get here)
              break;
          }       
       }        
     alarm.setRtcTimer(0, 0, TRACK_PING_TX_PERIOD);       // hour, min, sec go back to sleep until the next ping
     Snooze.hibernate( config_teensy36 );
   }
}

//************************************************************************************************
//************************************************************************************************
// Function to broadcast your location
// This function sends an APRS position report, including the 'comment' string. 
// First it configure the DAC to 12 but mode, 1.2V reference.
// Second, it switches on the required hardware (radio module) and waits for the 
// radio DC-DC converter to stabilize.   It the keys up the radio (PTT), waits for that to 
// stabilize and sends the AFSK encoded position using the digitcal to analog
// converter to generate to tones. 
// Finaly it disables the DAC to save power and switches off the boost converter for the radio
//
void broadcastLocation(const char *comment)
{
  int nAddresses; 
  // Enable the DAC that is used for generating the tone for the APRS radio
  analogWriteResolution(12);          // set DAC resolution to 12 bits
  analogReference(INTERNAL);          // use 1.2V internal reference (0V <= DAC Vout < 1.2V)
  analogWrite(A21, 0);                // Initialize DAC output to 0V
  
  digitalWrite(V_TX_SHUTDOWN, HIGH);  // Turn on 5V DC-DC converter for Radiometrix
   
  if (gps.altitude.meters() > 1524)   // If above 5000 feet (1524 meters) switch to a single hop path - only relevant in CONUS
    {
      // APRS recomendations for > 5000 feet is:
      // Path: WIDE2-1 is acceptable, but no path is preferred.
      nAddresses = 3;
      addresses[2].callsign = "WIDE2";
      addresses[2].ssid = 1;
    } 
  else 
    {
      // Below 1500 meters use a much more generous path (assuming a mobile station)
      // Path is "WIDE1-1,WIDE2-2"
      nAddresses = 4;
      addresses[2].callsign = "WIDE1";
      addresses[2].ssid = 1;
      addresses[3].callsign = "WIDE2";
      addresses[3].ssid = 2;
    }

  Fix_Time = gps.location.age();           // time (LSB=msec) since last GPS position
  if (Fix_Time > 99999) Fix_Time = 99999;  // Limit to 99,999 because its the largest value the TH-D74 radio can display
  APRS_XMIT_count++;                       // increment APRS message counter every time a message is sent (0-255, rolls over)

  aprs_send(addresses, nAddresses
      ,gps.date.day()           // does not seem to work
      ,gps.time.hour()
      ,gps.time.minute()
      ,gps.location.lat()       // degrees
      ,gps.location.lng()       // degrees
//    ,gps.altitude.meters()    // meters      
      ,Fix_Time                 // (TH-D74 Radio: ALT),new hijacked param: age of the GPS fix (msec), integer
//    ,gps.course.deg()         // in degrees (0-359)
      ,Ping_Array[1]            // (TH-D74 Radio: CSE),new hijacked param: Counts number of failed GPS positions, 0<= Ping_Array[1] <= 255
//    ,gps.speed.mph()          // in mph
      ,APRS_XMIT_count          // (TH-D74 Radio: SPD),new hijacked param: APRS transmission counter (0-255, rolls over) 
      ,SYMBOL_TABLE
      ,SYMBOL_CHAR
      ,comment);
          
  DAC0_C0 = ~DAC_C0_DACEN;            // DAC_C0_LPEN - disable DAC to save power
  digitalWrite(V_TX_SHUTDOWN, LOW);   // Turn off 5V DC-DC converter for Radiometrix 
}

//************************************************************************************************
//************************************************************************************************
//  This function turns on the GPS and looks for a position solution either until it has a solution,
//  or it reaches timeout seconds.
//  
//  If a position is found, it updates the global GPS position structure and returns true
//  If a position was not found, GPS position structure unchanged and returns false
//
//  timeout in seconds
//  millis() : returns a unsigned 32 bit integer, LSB = 1 msec, 0xFFFFFFFF is about 50 days
//           : initialized to 0x00000000 at power up
//
bool getGPS(long timeout, bool Power)
{ 
    long startTime = millis(); 
    digitalWrite(V_GPS_SHUTDOWN, HIGH);     // turn on GPS Power
    GPSSERIAL.begin(9600);                  // GPS receiver serial setup
    delay(500);
    
    while((gps.location.age() > 2000) && ((millis() - startTime) < timeout*1000l))  // wait for a GPS position that is less than 2s old or timeout
      {
       if (GPSSERIAL.available()) gps.encode(GPSSERIAL.read());                     // this sends incoming NEMA data to a parser, need to do this regularly
      }

    GPSSERIAL.end();
    
    if (Power == GPS_PWR_OFF) digitalWrite(V_GPS_SHUTDOWN, LOW);    // turn off GPS Power

    if (gps.location.age() < 3000)          
      {
       Update_Ping_Array();                 // update Ping Array with new valid GPS data 
       if (mode == TRACK) Ping_Array[1]=0;  // when in TRACK mode only, reset the missed fix counter everytime a valid GPS fix is found
       return true;      
      }
    else
      {
       if (Ping_Array[1] != 255) Ping_Array[1]++;    // increment counter that keeps track of missed GPS fixes (0-255), hold at 255
       return false;
      }
}

//************************************************************************************************
//************************************************************************************************
// This functions calculates scaled Lat\Lon that is used for sending position pings:
//
void Update_Ping_Array(void)
{ 
 float Angle_f;
 unsigned long int Angle_scaled;
  
// 0 deg <= Lat < 90 deg, decimal degreees, 24 bit unsigned word
 Angle_f = gps.location.lat();
 Angle_scaled = (unsigned long int) abs(Angle_f*GPS_24bit_SF);
 Angle_scaled = Angle_scaled & 0x00FFFFFF;       // only a 24 bit word, ensure upper bits are all zeros
 Ping_Array[2] = (byte) (Angle_scaled >> 16);    // Latitude MS byte 2 
 Ping_Array[3] = (byte) (Angle_scaled >> 8);     // Latitude byte 1
 Ping_Array[4] = (byte)  Angle_scaled;           // Latitude LS byte 0
    
// 0 deg <= Lon < 180 deg, deciamal degrees, 24 bit unsigned word                   
 Angle_f = gps.location.lng();
 Angle_scaled = (unsigned long int) abs(Angle_f*GPS_24bit_SF);
 Angle_scaled = Angle_scaled & 0x00FFFFFF;       // only a 24 bit word, ensure upper bits are all zeros
 Ping_Array[5] = (byte) (Angle_scaled >> 16);    // Longitude MS byte 2 
 Ping_Array[6] = (byte) (Angle_scaled >> 8);     // Longitude byte 1
 Ping_Array[7] = (byte)  Angle_scaled;           // Longitude LS byte 0      
}
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

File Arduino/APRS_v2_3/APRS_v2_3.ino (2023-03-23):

// Automatic Packet Rreporting System (APRS) 
// Compile at 24Mhz to minimize power consumption
#include <Adafruit_MPL3115A2.h>   //for the pressurse sensor
#include <Wire.h> 
#include <Snooze.h>               //For low power hibernate
#include <TinyGPS++.h>            //GPS parsing library
#include <aprs.h>                 //APRS encoding and transmission library
#include <WProgram.h>

/* These are the variables you may want to change before a flight */
#define FLIGHT_NAME "MCM1028"      //Flight name in APRS message

// Mode 0 (Flight) parameters
#define FLIGHT_PERIOD 15              // How many minutes to be in active flight mode before sleeping
#define FLIGHT_APRS_TX_PERIOD 3       // How often to send an APRS position in minutes in flight mode

// Mode 1 (Hibernate) parameter
#define HIBERNATE_PERIOD 3       // How many days to sleep before beginning transmission

// Mode 2 (Track) parameters
#define TRACK_APRS_TX_PERIOD 3   // How often to send APRS position in minutes in track mode
#define TRACK_GPS_PERIOD 1        // How often to look for a GPS position in hours in track mode
#define TRACK_PING_TX_PERIOD 10    // how often to send a 'beep' in seconds
#define PING_DURATION 1000          // How long the ping transmission is in ms

#define debug //uncomment this for console debug

// Load drivers for the snooze code and configure snooze block.  We only us the RTC alamr so that is all we need to load. 
SnoozeAlarm  alarm;
SnoozeBlock config_teensy36(alarm); 

/* Pin Configuration */
#define V_TX_SHUTDOWN 23        // Enable pin for 3.6 to 5V boost converter
#define V_GPS_SHUTDOWN 30       // Power switch on 3.3v line to GPS and Pressure Sensor
#define TX_ENABLE 2             // Pull this high to turn on the transmitterpush (Push To Talk function)

/* APRS Configuration */
// Set your callsign and SSID here. Common values for the SSID are
#define S_CALLSIGN      "KE0PRP"
#define S_CALLSIGN_ID   11          // 11 is usually for balloons
                                    // Destination callsign: APRS (with SSID=0) is usually okay.
#define D_CALLSIGN      "APRS"
#define D_CALLSIGN_ID   0
                                    // Symbol Table: '/' is primary table '\' is secondary table
#define SYMBOL_TABLE '/' 
                                    // Primary Table Symbols: /O=balloon, /-=House, /v=Blue Van, />=Red Car
#define SYMBOL_CHAR 'O'

struct PathAddress addresses[] = {
  {(char *)D_CALLSIGN, D_CALLSIGN_ID},    // Destination callsign
  {(char *)S_CALLSIGN, S_CALLSIGN_ID},    // Source callsign
  {(char *)NULL, 0},                      // Digi1 (first digi in the chain)
  {(char *)NULL, 0}                       // Digi2 (second digi in the chain)
};

#define GPSSERIAL Serial1 //UBlox GPS is on Serial1
Adafruit_MPL3115A2 baro = Adafruit_MPL3115A2();
TinyGPSPlus gps;

//Table for DAC generated sine wave for transmittin 'pings'
int sin_Wave[] = {2045,2173,2301,2428,2553,2676,2797,2915,3030,3140,3247,3348,
              3444,3535,3620,3699,3771,3837,3895,3946,3989,4025,4053,4073,
              4085,4090,4085,4073,4053,4025,3989,3946,3895,3837,3771,3699,
              3620,3535,3444,3348,3247,3140,3030,2915,2797,2676,2553,2428,
              2301,2173,2044,1916,1788,1661,1536,1413,1292,1174,1059,949,842,
              741,645,554,469,390,318,252,194,143,100,64,36,16,4,0,4,16,36,
              64,100,143,194,252,318,390,469,554,645,741,842,949,1059,1174,
              1292,1413,1536,1661,1788,1916}; 

int flight_APRS_packets = 0;      // initialize Mode 0 (Flight) loop counter
int days_in_hibernate = 0;        // initialize Mode 1 (Hibernate) days counter

long pings_sent = 5;
int track_APRS_packets = 0;

int mode = 0;   // Mode variable
                // Mode 0 = Flight mode, send APRS often
                // Mode 1 = Sleep Mode, hibernate for X days
                // Mode 2 = Track Mode, pings with occasional APRS


void setup()
{
  Serial.begin(9600); // For debugging output over the USB port
  /* GPS Setup */
   GPSSERIAL.begin(9600); //GPS receiver setup

   pinMode(LED_BUILTIN, OUTPUT);
   pinMode(V_TX_SHUTDOWN, OUTPUT);
   pinMode(V_GPS_SHUTDOWN, OUTPUT);
   pinMode(TX_ENABLE,OUTPUT);

   /* Start with everything off */
   digitalWrite(V_TX_SHUTDOWN, LOW);
   digitalWrite(V_GPS_SHUTDOWN, LOW);
   digitalWrite(TX_ENABLE, LOW);
   analogWriteResolution(12);
   analogReference(INTERNAL);

  /* Blink 5 times on power up so we know it is working */
  for (int i = 0; i < 5 ; i++)
  {
    digitalWrite(LED_BUILTIN, HIGH);
    delay(200);
    digitalWrite(LED_BUILTIN, LOW);
    delay(200);
  }

  Serial.println("Begin");
  Serial.println(FLIGHT_NAME);
  delay(500);  

  
  /* Set up the APRS code */
  aprs_setup(50,        // number of preamble flags to send
       TX_ENABLE,       // Use PTT pin
       10,              // ms to wait after PTT to transmit
       0, 0             // No VOX ton
       );
  
  Serial.println("Entering_Flight_Mode");
  delay(500);  
  broadcastLocation( "TRACKER_ON_3" ); // XMT Tracker ON message to the radio
  delay(500);
}

/* Main loop has 3 blocks of code that are exectued dependign on the 
 *  mode that the tracker is in.  
 */

void loop()
{
 /* Flight Mode
  * Only sends APRS positions, no pings. Updates GPS position for every APRS packet
  * Average Current consumption is 25mA
  */
 if (mode == 0) 
 {
    getGPS(120);                      // try for 2 minutes to get a GPS Position
    broadcastLocation( FLIGHT_NAME ); //Send the location by APRS

    if (flight_APRS_packets > int(float(FLIGHT_PERIOD)/float(FLIGHT_APRS_TX_PERIOD)))
    {
      mode = 1;
      broadcastLocation( "MODE=1=SLEEP" ); // XMT mode changing to MODE=1 (Hebernate)
    }
    flight_APRS_packets++;
      
    alarm.setRtcTimer(0, FLIGHT_APRS_TX_PERIOD,0);    // hour, min, sec
    Snooze.hibernate( config_teensy36 );
 }   
 
 /* Hibernate Mode 
  * Wakes up once per day to update the counter of how many days have elapsed
  * Otherwise doesn't do anything. 
  * Avergae Current 0.5 mA
  */
 if (mode == 1) 
 {
    days_in_hibernate++;
    if (days_in_hibernate > HIBERNATE_PERIOD)
    {
      mode = 2;                               // Go to Track Mode when hibernated period completed
      getGPS(300);                            //try for 5 minutes to get a GPS Position  
      broadcastLocation( "MODE=2=TRACK" );    // Send MODE=2=Track to the radio  
    }
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

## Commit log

2023-03-23 Arduino code imported from _VHF Tracker Documentation_
    This was the "Arduino Code" directory from the
    file "VHF Tracker Documentation.zip", from Lars.
2023-03-23 Power calculation spreadsheets imported from VHF Tracker Documentation
    This was the _Power Calculator_ directory from the
    file _VHF Tracker Documentation.zip_, from Lars.
    [Detailed Power Calc 25 May.xlsx, Detailed Power Calc.xlsx, Power Consumption Matrix.xlsx]
2023-03-26 Add flight id to all APRS messages
    - A couple of the APRS meesage IDs had not been updated
    to include the flight number.
    - Add print the source file path to the console
    at startup.
2023-03-26 Board revison verification
    Make sure that one of TRACKER_REVA|TRACKER_REVB is defined.
    Print the board revision to the console.
2023-03-26 Print the build time at startup
2023-03-26 Shorten low power times and remove print stmts
    [TrackerTest01.ino]
2023-03-27 Prototype the trackerfinder app
2023-03-27 Fix close behavior for the blocking read
    TrackerAx25 thread has a blocking read, which blocks the
    event loop. This makes it hard to shutdown gracefully, either
    with a SIG_INT or a close event. Capture both of these,
    terminate TrackerAx25, and exit.
2023-03-29 Tracker power budget for flight 1038
    Launch date 2 April 2023
    Wake up date 1 November 2023
2023-03-29 Display device name in main window status bar
2023-03-29 Rename Arduino directory
2023-03-31 Add Arduino program for flight 1041
2023-04-02 Correct a comment about the hibernate dates
    [FLT_MCM1040.ino]
2023-04-03 Save the battery holder design files
    [Battery Holder v27.f3d, Battery Holder v27.stl]
2023-04-09 Update power calcs for recent flights
2023-04-12 Move to RevA directory
    [Battery Holder v27.f3d, Battery Holder v27.stl]
2023-04-12 RevB battery holder files
    [Rev B Battery Holder v82.3mf, Rev B Battery Holder v82.stl, Rev B Battery Holder v83.f3z]
2023-04-13 remove old versions of Rev B bat holder
    [Rev B Battery Holder v82.3mf, Rev B Battery Holder v82.stl, Rev B Battery Holder v83.f3z]
2023-04-13 Current Rev B battery holder
    [Rev B Battery Holder Drill Guide v98.stl, Rev B Battery Holder v100.f3z, Rev B Battery Holder v99.stl]
2023-04-17 Switch to pyserial which works for windows
2023-04-17 Change directory name
    [Battery Holder v27.f3d, Battery Holder v27.stl, Rev B Battery Holder Drill Guide v98.stl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]
2023-04-17 Battery holder for Rev B tracker
    [Rev B Battery Holder Drill Guide v98.stl, Rev B Battery Holder v99.stl]
2023-04-17 Mk II battery holder for Rev B tracker (w/o soldered battery leads)
    [RevB Bat Box Mk II v36.3mf, RevB Bat Box Mk II v36.stl]
2023-04-17 Removed diagnostic prints
2023-04-17 Document the msg timing and switch to Rev B tracker
2023-04-17 Renders for Rev B Mk I battery holder
2023-04-18 Power spreadsheet for flight 1044
2023-04-18 Fix the Rev B encoded ping +5V power control
    [FLT_MCM1045.ino]
2023-04-18 Fix the encoded ping +5V power control
    And add some comments.
    [PingTest01.ino, TrackerTest01.ino, TrackerTest02.ino]
2023-04-18 Opps, Arduino folder and file must share the same name
2023-04-25 Flt 1045 power budget
